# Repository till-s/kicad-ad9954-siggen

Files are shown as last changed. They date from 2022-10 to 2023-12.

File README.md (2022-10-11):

# Simple 1Hz-100MHz Signal Generator with AD9954

This project implements a simple sine-wave generator from a few Hz
to ~100MHz. The Reference/sampling frequency is 400MHz.
The output is buffered by a OP859 amplifier which does level-shifting,
and differential to single-ended conversion.

An analog LPF at the output supresses higher harmonics and provides
the DC-coupled signal into a 50 Ohm load (i.e., the filter was
designed for a 50Ohm termination). The ripple over the frequency range
is in the order of 1dB.

The output amplitude can be (digitally) scaled from ~1Vp (0.7V RMS) down
to 0Vp.

The AD9954 is programmed via USB (USB-SPI converter) by a simple python
software (in the sw/ subdirectory). Power is supplied by USB as well.

The assembled PCB fits into a Hammond 1455D601 extruded aluminum box
(60mm x 42.5mm x 23mm).

The PCB requires 4 layers.

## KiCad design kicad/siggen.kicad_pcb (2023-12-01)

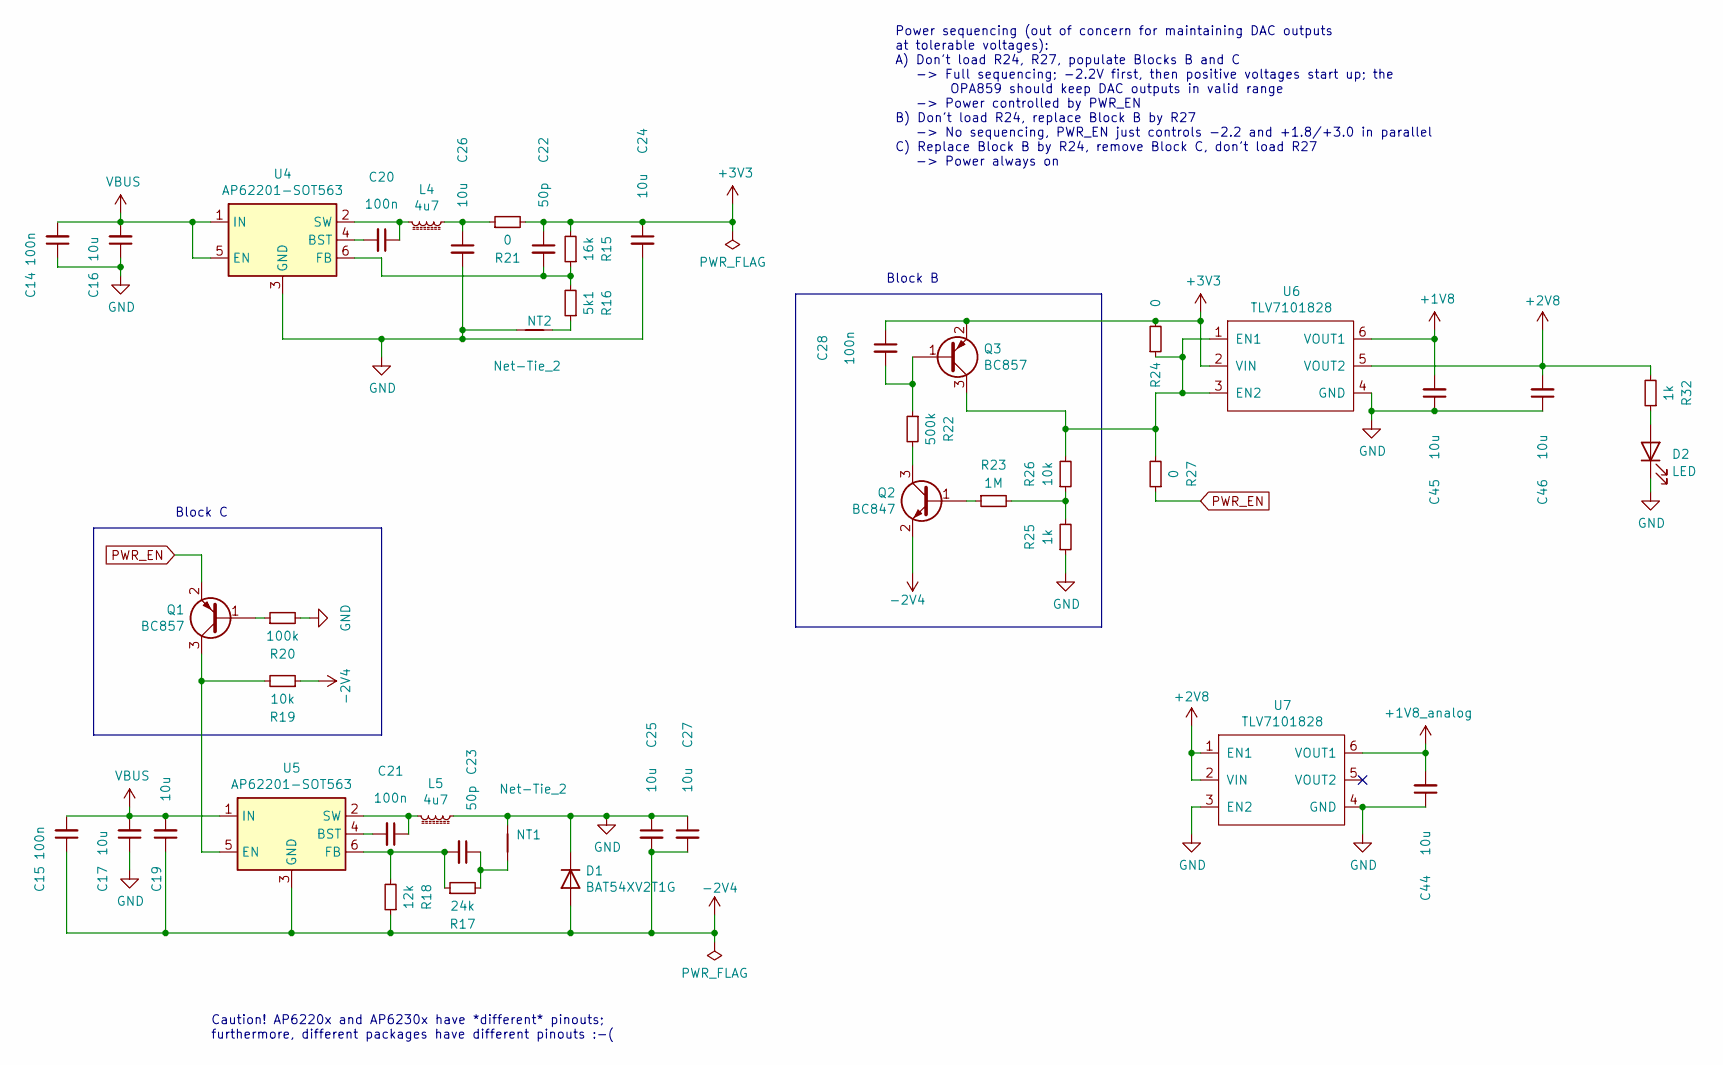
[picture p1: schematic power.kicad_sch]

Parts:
C14, C15, C20, C21, C28: 100n; C_0603_1608Metric
C16, C17, C19, C24, C25, C26, C27, C44, C45, C46: 10u; C_1206_3216Metric
C22, C23: 50p; C_0603_1608Metric
D1: BAT54XV2T1G; D_SOD-523
D2: LED; LED_0603_1608Metric
L4, L5: 4u7; L_Taiyo-Yuden_NR-50xx
NT1, NT2: Net-Tie_2; NetTie-2_SMD_Pad0.5mm
Q1, Q3: BC857; SOT-23
Q2: BC847; SOT-23
R15: 16k; R_0603_1608Metric
R16: 5k1; R_0603_1608Metric
R17: 24k; R_0603_1608Metric
R18: 12k; R_0603_1608Metric
R19, R26: 10k; R_0603_1608Metric
R20: 100k; R_0603_1608Metric
R21, R24, R27: 0; R_0603_1608Metric
R22: 500k; R_0603_1608Metric
R23: 1M; R_0603_1608Metric
R25, R32: 1k; R_0603_1608Metric
U4, U5: AP62201-SOT563; SOT-563-adjusted
U6, U7: TLV7101828; WSON-6_1.5x1.5mm_P0.5mm

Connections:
+1V8: C45.2, U6.6 (VOUT1); also elsewhere on the board
+1V8_analog: C44.2, U7.6 (VOUT1); also elsewhere on the board
+2V8: C46.2, R32.2, U6.5 (VOUT2), U7.1 (EN1), U7.2 (VIN); also elsewhere on the board
+3V3: C22.1, C24.1, C28.1, Q3.2 (E), R15.2, R21.2, R24.2, U6.2 (VIN); also elsewhere on the board
-2V4: C15.1, C19.1, C25.2, C27.2, D1.2 (A), Q2.2 (E), R18.1, R19.1, U5.3 (GND); also elsewhere on the board
GND: C14.1, C16.1, C17.1, C24.2, C25.1, C26.2, C27.1, C44.1, C45.1, C46.1, D1.1 (K), D2.1 (K), L5.1, NT1.1, NT2.2, R20.2, R25.1, U4.3 (GND), U6.4 (GND), U7.3 (EN2), U7.4 (GND); also elsewhere on the board
unnamed: C23.1, NT1.2, R17.2
unnamed: C26.1, L4.1, R21.1
unnamed: D2.2 (A), R32.1
unnamed: NT2.1, R16.1
unnamed: Q1.1 (B), R20.1
unnamed: Q1.3 (C), R19.2, U5.5 (EN)
unnamed: Q2.1 (B), R23.1
unnamed: Q2.3 (C), R22.2
unnamed: C28.2, Q3.1 (B), R22.1
unnamed: Q3.3 (C), R24.1, R26.2, R27.2, U6.1 (EN1), U6.3 (EN2)
unnamed: R23.2, R25.2, R26.1
unnamed: C20.2, U4.4 (BST)
unnamed: C22.2, R15.1, R16.2, U4.6 (FB)
unnamed: C20.1, L4.2, U4.2 (SW)
unnamed: C21.2, U5.4 (BST)
unnamed: C23.2, R17.1, R18.2, U5.6 (FB)
unnamed: C21.1, L5.2, U5.2 (SW)
PWR_EN: Q1.2 (E), R27.1; also elsewhere on the board
VBUS: C14.2, C15.2, C16.2, C17.2, C19.2, U4.1 (IN), U4.5 (EN), U5.1 (IN); also elsewhere on the board

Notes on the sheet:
Block B
Power sequencing (out of concern for maintaining DAC outputs at tolerable voltages): A) Don't load R24, R27, populate Blocks B and C -> Full sequencing; -2.2V first, then positive voltages start up; the OPA859 should keep DAC outputs in valid range -> Power controlled by PWR_EN B) Don't load R24, r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
Block C
Caution! AP6220x and AP6230x have *different* pinouts; furthermore, different packages have different pinouts :-(

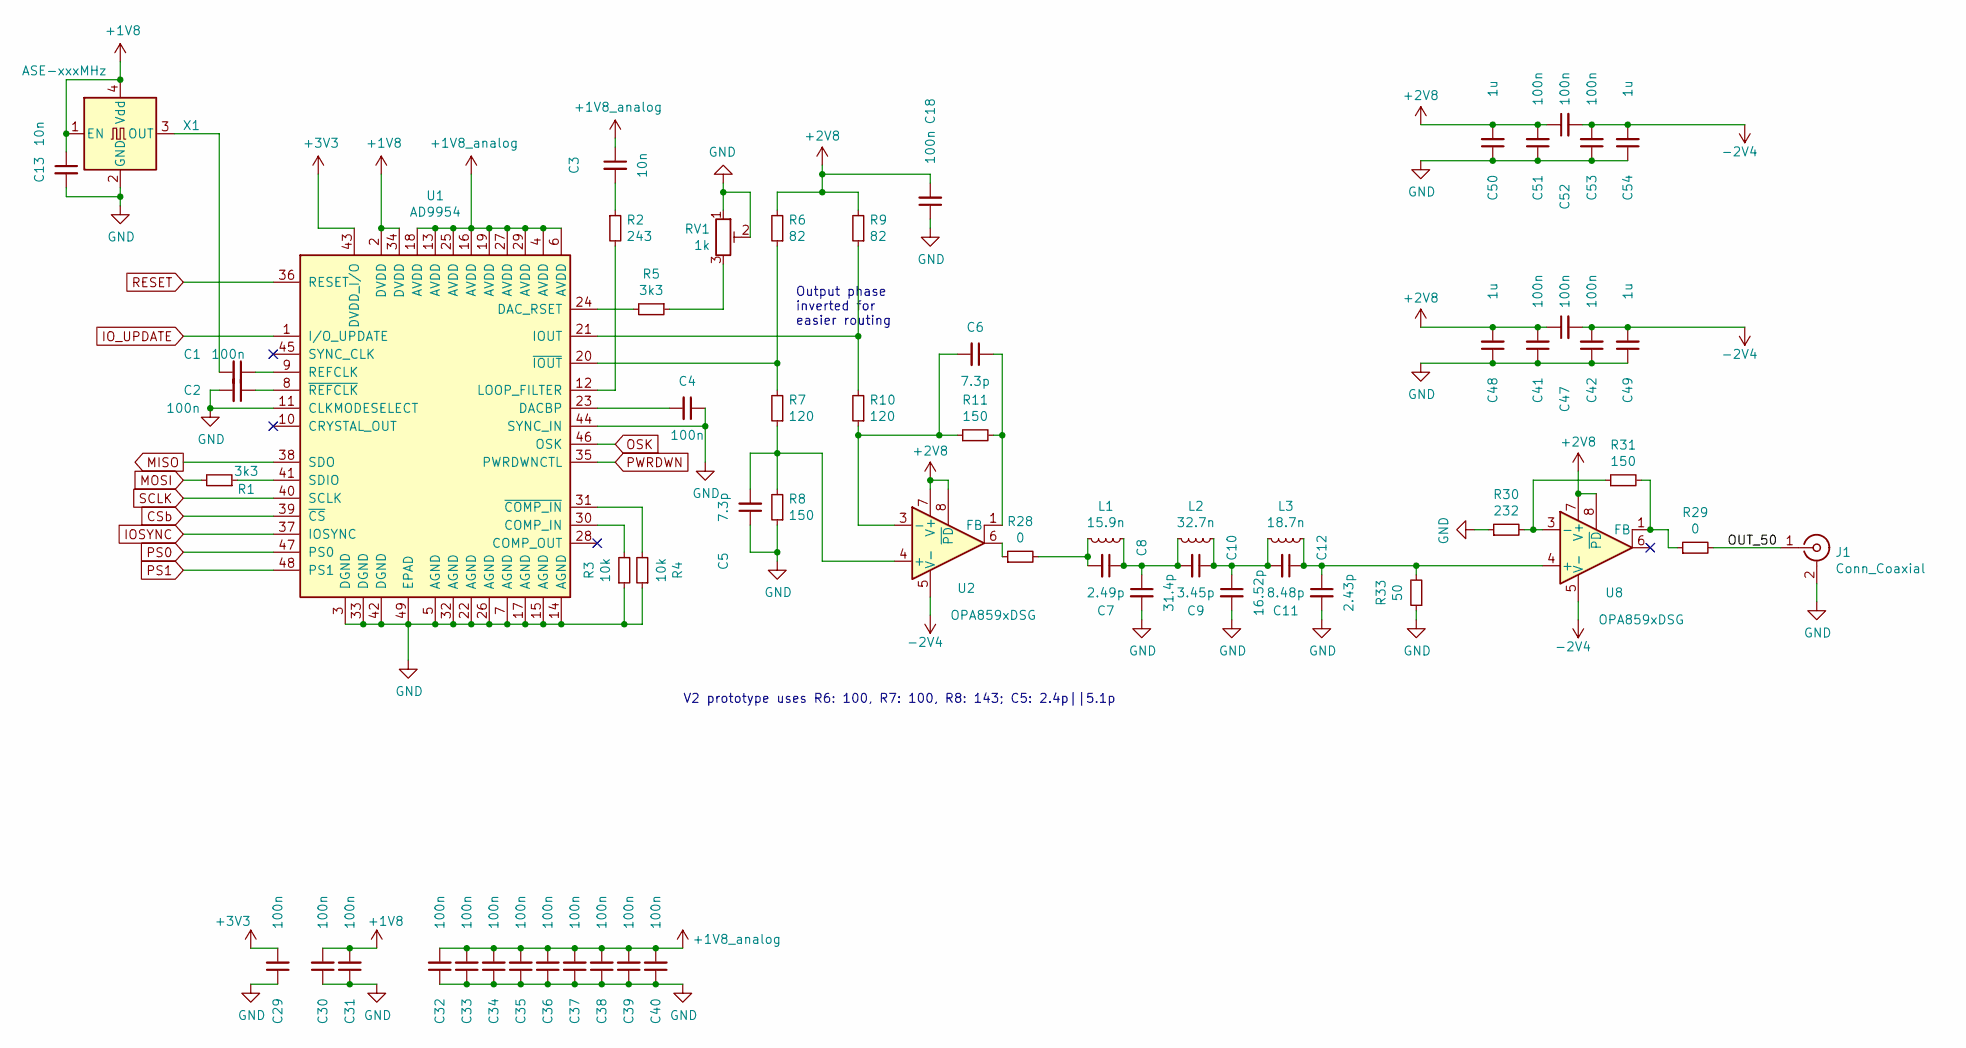
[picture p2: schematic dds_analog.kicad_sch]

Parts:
C1, C2: 100n; C_0603_1608Metric
C3, C13: 10n; C_0603_1608Metric
C4, C18, C29, C30, C31, C32, C33, C34, C35, C36, C37, C38, C39, C40, C41, C42, C47, C51, C52, C53: 100n; C_0402_1005Metric
C5, C6: 7.3p; C_0402_1005Metric
C7: 2.49p; C_0402_1005Metric
C8: 31.4p; C_0603_1608Metric
C9: 3.45p; C_0402_1005Metric
C10: 16.52p; C_0402_1005Metric
C11: 8.48p; C_0402_1005Metric
C12: 2.43p; C_0402_1005Metric
C48, C49, C50, C54: 1u; C_0805_2012Metric
J1: Conn_Coaxial; BNC_Molex_0731713150
L1: 15.9n; L_0603_1608Metric
L2: 32.7n; L_0603_1608Metric
L3: 18.7n; L_0603_1608Metric
R1, R5: 3k3; R_0603_1608Metric
R2: 243; R_0603_1608Metric
R3, R4: 10k; R_0603_1608Metric
R6, R9: 82; R_0402_1005Metric
R7, R10: 120; R_0402_1005Metric
R8, R11, R31: 150; R_0402_1005Metric
R28, R29: 0; R_0402_1005Metric
R30: 232; R_0402_1005Metric
R33: 50; R_0402_1005Metric
RV1: 1k; Bourns_PVG5A_Trimmer
U1: AD9954; TQFP-48-1EP_7x7mm_P0.5mm_EP3.5x3.5mm
U2, U8: OPA859xDSG; WSON-8-1EP_2x2mm_P0.5mm_EP0.9x1.6mm
X1: ASE-xxxMHz; Oscillator_SMD_Abracon_ASE-4Pin_3.2x2.5mm

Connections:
+1V8: C13.1, C30.2, C31.2, U1.2 (DVDD), U1.34 (DVDD), X1.1 (EN), X1.4 (Vdd); also elsewhere on the board
+1V8_analog: C3.1, C32.2, C33.2, C34.2, C35.2, C36.2, C37.2, C38.2, C39.2, C40.2, U1.4 (AVDD), U1.6 (AVDD), U1.13 (AVDD), U1.16 (AVDD), U1.18 (AVDD), U1.19 (AVDD), U1.25 (AVDD), U1.27 (AVDD), U1.29 (AVDD); also elsewhere on the board
+2V8: C18.2, C41.2, C47.1, C48.2, C50.2, C51.2, C52.1, R6.2, R9.2, U2.7 (V+), U2.8 (~PD), U8.7 (V+), U8.8 (~PD); also elsewhere on the board
+3V3: C29.2, U1.43 (DVDD_I/O); also elsewhere on the board
-2V4: C42.2, C47.2, C49.2, C52.2, C53.2, C54.2, U2.5 (V-), U2.9 (V-), U8.5 (V-), U8.9 (V-); also elsewhere on the board
/dds_analog/OUT_50: J1.1 (In), R29.2
CSb: U1.39 (~CS); also elsewhere on the board
GND: C2.2, C4.1, C5.1, C8.2, C10.2, C12.2, C13.2, C18.1, C29.1, C30.1, C31.1, C32.1, C33.1, C34.1, C35.1, C36.1, C37.1, C38.1, C39.1, C40.1, C41.1, C42.1, C48.1, C49.1, C50.1, C51.1, C53.1, C54.1, J1.2 (Ext), R3.1, R4.1, R8.1, R30.1, R33.1, RV1.1, RV1.2, U1.3 (DGND), U1.5 (AGND), U1.7 (AGND), U1.11 (CLKMODESELECT), U1.14 (AGND), U1.15 (AGND), U1.17 (AGND), U1.22 (AGND), U1.26 (AGND), U1.32 (AGND), U1.33 (DGND), U1.42 (DGND), U1.44 (SYNC_IN), U1.49 (EPAD), X1.2 (GND); also elsewhere on the board
IOSYNC: U1.37 (IOSYNC); also elsewhere on the board
IO_UPDATE: U1.1 (I/O_UPDATE); also elsewhere on the board
MISO: U1.38 (SDO); also elsewhere on the board
MOSI: R1.2; also elsewhere on the board
unnamed: C3.2, R2.1
unnamed: C7.1, C8.1, C9.2, L1.1, L2.2
unnamed: C7.2, L1.2, R28.2
unnamed: C9.1, C10.1, C11.2, L2.1, L3.2
unnamed: R5.1, RV1.3
unnamed: R28.1, U2.6
unnamed: R3.2, U1.30 (COMP_IN)
unnamed: C4.2, U1.23 (DACBP)
unnamed: R5.2, U1.24 (DAC_RSET)
unnamed: R9.1, R10.2, U1.21 (IOUT)
unnamed: R2.2, U1.12 (LOOP_FILTER)
unnamed: C1.1, U1.9 (REFCLK)
unnamed: R1.1, U1.41 (SDIO)
unnamed: R4.2, U1.31 (~COMP_IN)
unnamed: R6.1, R7.2, U1.20 (~IOUT)
unnamed: C2.1, U1.8 (~REFCLK)
unnamed: C5.2, R7.1, R8.2, U2.4 (+)
unnamed: C6.2, R10.1, R11.1, U2.3 (-)
unnamed: C6.1, R11.2, U2.1 (FB)
unnamed: C11.1, C12.1, L3.1, R33.2, U8.4 (+)
unnamed: R30.2, R31.1, U8.3 (-)
unnamed: R29.1, R31.2, U8.1 (FB)
unnamed: C1.2, X1.3 (OUT)
OSK: U1.46 (OSK); also elsewhere on the board
PS0: U1.47 (PS0); also elsewhere on the board
PS1: U1.48 (PS1); also elsewhere on the board
PWRDWN: U1.35 (PWRDWNCTL); also elsewhere on the board
RESET: U1.36 (RESET); also elsewhere on the board
SCLK: U1.40 (SCLK); also elsewhere on the board

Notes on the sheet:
V2 prototype uses R6: 100, R7: 100, R8: 143; C5: 2.4p||5.1p
Output phase inverted for easier routing

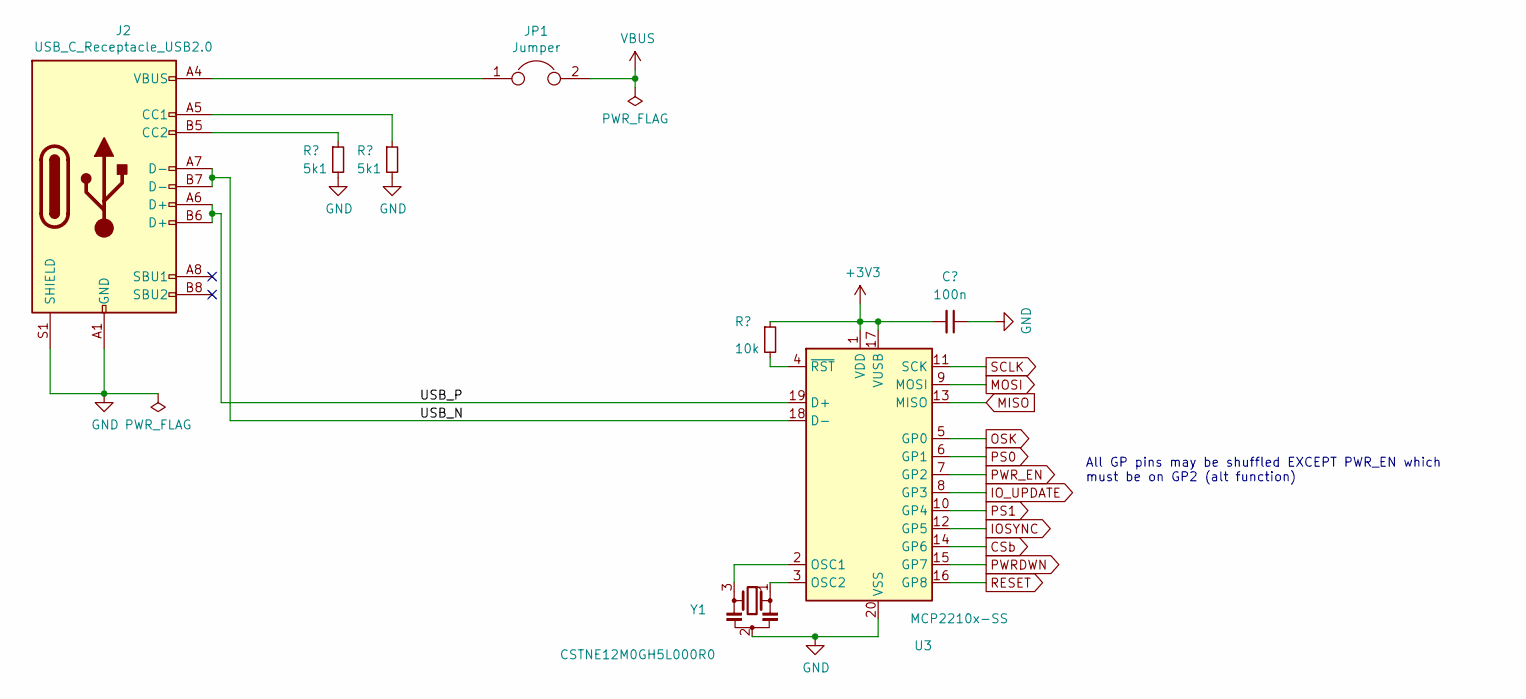
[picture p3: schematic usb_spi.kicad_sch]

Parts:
C43: 100n; C_0603_1608Metric
J2: USB_C_Receptacle_USB2.0; USB_C_Receptacle_Molex_2171790001_16P_TopMnt_Horizontal
JP1: Jumper; PinHeader_1x02_P1.27mm_Vertical_reduced_crtyd
R12, R13: 5k1; R_0603_1608Metric
R14: 10k; R_0603_1608Metric
U3: MCP2210x-SS; SSOP-20_5.3x7.2mm_P0.65mm
Y1: CSTNE12M0GH5L000R0; Resonator_SMD_muRata_CSTxExxV-3Pin_3.0x1.1mm

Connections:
+3V3: C43.2, R14.1, U3.1 (VDD), U3.17 (VUSB); also elsewhere on the board
/usb_spi/USB_N: J2.A7 (D-), J2.B7 (D-), U3.18 (D-)
/usb_spi/USB_P: J2.A6 (D+), J2.B6 (D+), U3.19 (D+)
CSb: U3.14 (GP6); also elsewhere on the board
GND: C43.1, J2.A1 (GND), J2.A12 (GND), J2.B1 (GND), J2.B12 (GND), J2.S1 (SHIELD), R12.2, R13.2, U3.20 (VSS), Y1.2; also elsewhere on the board
IOSYNC: U3.12 (GP5); also elsewhere on the board
IO_UPDATE: U3.8 (GP3); also elsewhere on the board
MISO: U3.13 (MISO); also elsewhere on the board
MOSI: U3.9 (MOSI); also elsewhere on the board
unnamed: J2.A5 (CC1), R13.1
unnamed: J2.B5 (CC2), R12.1
unnamed: J2.A4 (VBUS), J2.A9 (VBUS), J2.B4 (VBUS), J2.B9 (VBUS), JP1.1
unnamed: U3.2 (OSC1), Y1.3
unnamed: U3.3 (OSC2), Y1.1
unnamed: R14.2, U3.4 (~RST)
OSK: U3.5 (GP0); also elsewhere on the board
PS0: U3.6 (GP1); also elsewhere on the board
PS1: U3.10 (GP4); also elsewhere on the board
PWRDWN: U3.15 (GP7); also elsewhere on the board
PWR_EN: U3.7 (GP2); also elsewhere on the board
RESET: U3.16 (GP8); also elsewhere on the board
SCLK: U3.11 (SCK); also elsewhere on the board
VBUS: JP1.2; also elsewhere on the board

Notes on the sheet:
All GP pins may be shuffled EXCEPT PWR_EN which must be on GP2 (alt function)

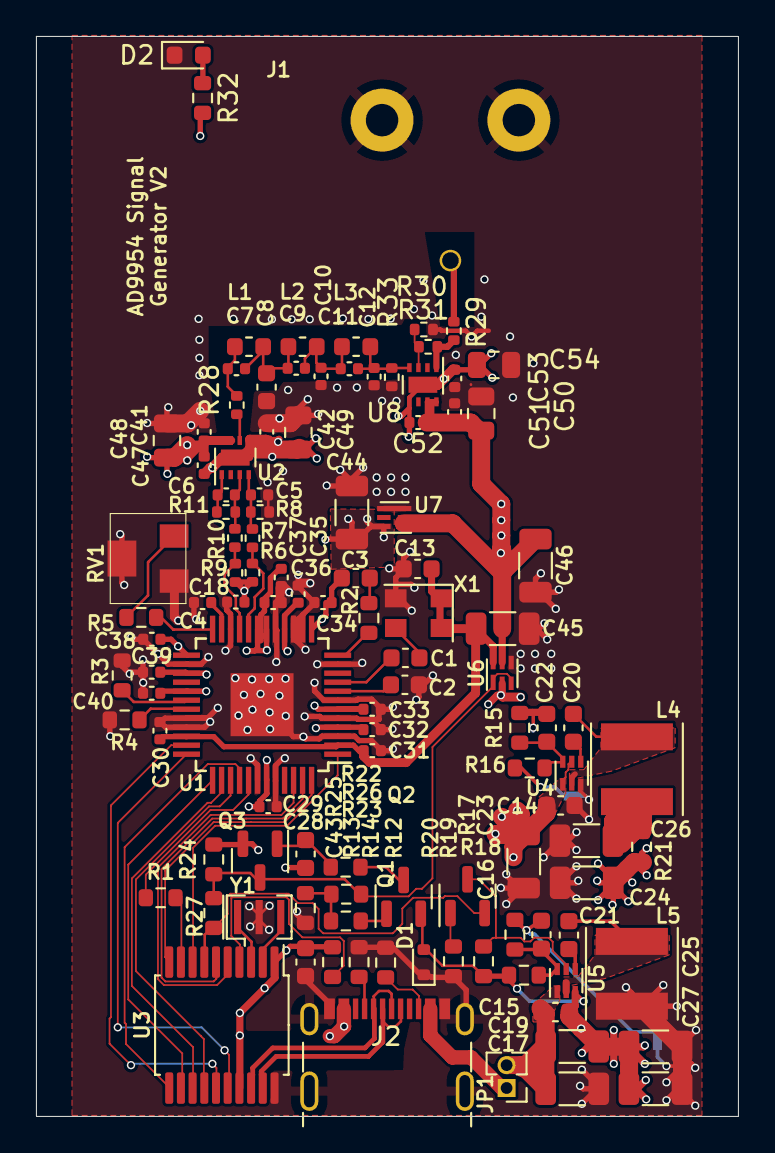
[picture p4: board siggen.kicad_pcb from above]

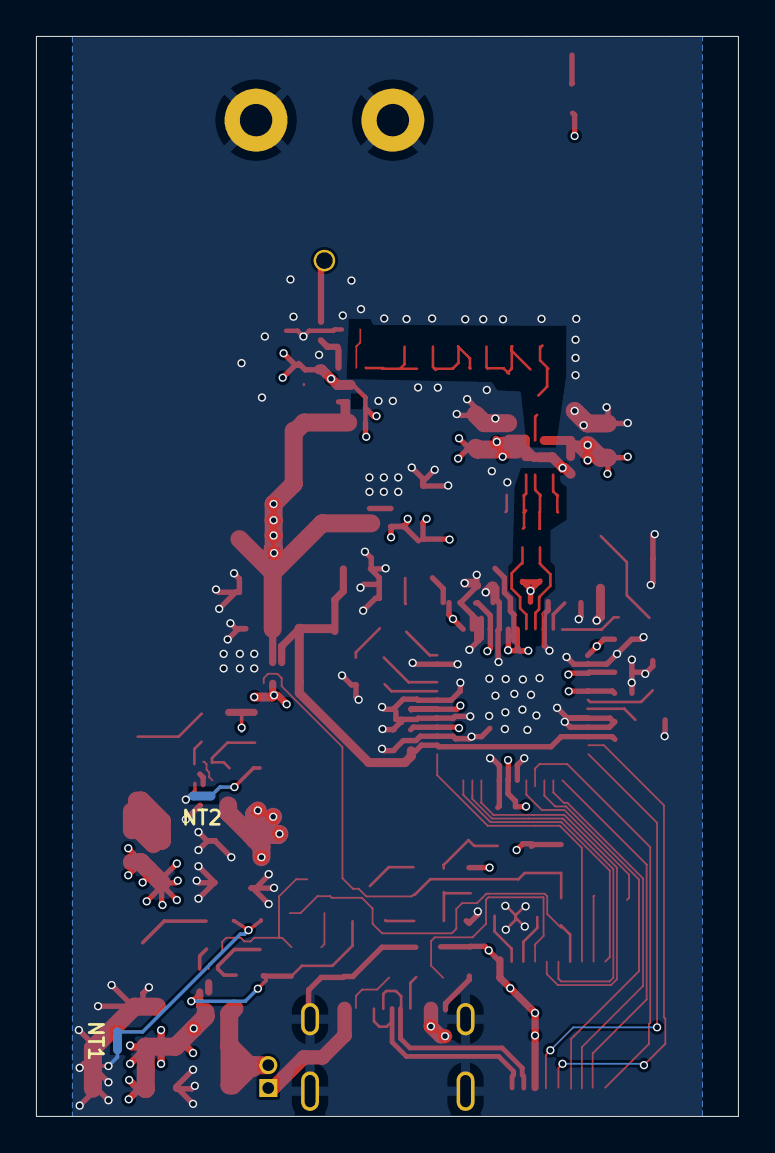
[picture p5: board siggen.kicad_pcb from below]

Board: 4 copper layers, 39.0 x 60.0 mm, 113 parts (2 on the bottom side), 68 nets.

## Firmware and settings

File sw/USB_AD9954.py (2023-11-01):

#!/usr/bin/env python3
import hidapi

class SigGen(object):
  PIN_OSK       = 0
  PIN_PS0       = 1
  PIN_PWR_EN    = 2
  PIN_IO_UPDATE = 3

  PIN_PS1       = 4
  PIN_IOSYNC    = 5
  PIN_CSb       = 6
  PIN_PWRDWN    = 7
  # Reset / PIN8 is input only -> shorted to PIN_PWRDWN on V1 board
  # via solder bridge

  SPI_MODE = 0

  SPI_DIR_READ       = 0x80

  CMD_RD_GPIO_SETUP  = 0x20
  CMD_WR_GPIO_SETUP  = 0x21
  CMD_RD_GPIO_DIR    = 0x33
  CMD_WR_GPIO_DIR    = 0x32
  CMD_RD_GPIO_VALUE  = 0x31
  CMD_WR_GPIO_VALUE  = 0x30
  CMD_RD_SPI_SETUP   = 0x41
  CMD_WR_SPI_SETUP   = 0x40
  CMD_SPI_XFER       = 0x42
  CMD_SPI_CANCEL     = 0x11

  REG_CFR1           = 0x00
  CFR1_SDIO_IN       = (1<< 9)
  CFR1_OSK_EN        = (1<<25)
  CFR1_OSK_AUTO      = (1<<24)
  CFR1_CMP_PWRDWN    = (1<< 6)
  CFR1_SYNC_CLK_DIS  = (1<< 1)

  REG_CFR2           = 0x01
  CFR2_VCO_RNG_HI    = (1<< 2)
  CFR2_SHF_REF_MUL   = 3

  REG_ASF            = 0x02

  REG_FTW0           = 0x04

  REF_CLK_HZ         = 25.0e6

  def __init__(self, serial=None, dbg=False):
    self.dbg_       = dbg
    self.dev_       = hidapi.Device(vendor_id=0x4d8, product_id=0xde, serial_number=serial)
    self.rdGpio_    = bytearray(64)
    self.rdGpio_[0] = self.CMD_RD_GPIO_SETUP
    self.wrGpio_    = bytearray(64)
    self.wrGpio_[0] = self.CMD_WR_GPIO_VALUE
    rsp = self._io_(self.rdGpio_)
    if ( rsp[1] != 0 ):
      raise RuntimeError("Reading GPIO Status - error response")
    setGpio = bytearray(64)
    for i in range(64):
      setGpio[i] = rsp[i]
    setGpio[0] = self.CMD_WR_GPIO_SETUP
    setGpio[1] = 0
    setGpio[2] = 0
    setGpio[3] = 0
    for i in range(4, 4+9):
      setGpio[i] = 0   # GPIO
    setGpio[13] = 0x00 | (1<<self.PIN_PWR_EN) # all outputs zero, except PWR_EN
    setGpio[14] &= 0xfe
    setGpio[15] = 0x00 # all GPIO outputs
    setGpio[16] &= 0xfe
    self.wrGpio_[4] = setGpio[13]
    self._io_(setGpio, True)
    cmd = bytearray(64)
    cmd[0] = self.CMD_RD_SPI_SETUP
    rsp = self._io_(cmd)
    self.spiParms_ = bytearray(64)
    self.spiParms_[0] = self.CMD_WR_SPI_SETUP
    self.spiParms_[4:]= rsp[4:]
    self.spiParms_[20]= self.SPI_MODE
    self.sendSpiParms()
    cfr1  = self.CFR1_SDIO_IN
    cfr1 |= self.CFR1_OSK_EN 
    cfr1 |= self.CFR1_CMP_PWRDWN 
    cfr1 |= self.CFR1_SYNC_CLK_DIS
    self.regWrite(self.REG_CFR1, cfr1)
    self.setRefClk(400.0E6)

  def setRefClk(self, rate):
    m = int( round( rate/self.REF_CLK_HZ ) )
    if ( m > 20 ):
      raise RuntimeError("setRefClk() -- requested rate too high")
    if ( m < 4 ):
      m = 1
    self.sysClkHz_ = m * self.REF_CLK_HZ
    print("System Clock: {:g}".format(self.sysClkHz_))
    cfr2 = self.regRead( self.REG_CFR2 )
    cfr2 &= ~ 0xfc
    cfr2 |= (m << self.CFR2_SHF_REF_MUL)
    if ( self.sysClkHz_ > 250.0E6 ):
      cfr2 |= self.CFR2_VCO_RNG_HI
    self.regWrite( self.REG_CFR2, cfr2 )

  def setAmplitudeScale(self, scl):
    if ( scl < 0 or scl > 1.0 ):
      raise ValueError("SigGen.setAmplitudeScale() -- scale factor not in 0..1")
    v = self.regRead( self.REG_ASF )
    v &= ~0x3fff
    v |= int(0x3fff*scl)
    self.regWrite( self.REG_ASF, v)

  def getAmplitudeScale(self):
    v = self.regRead( self.REG_ASF )
    return float(v & 0x3fff)/0x3fff

  def setFrequencyHz(self, f, ftw1 = False):
    ftw = int(round(f/self.sysClkHz_ * 2.0**32))
    if ( ftw < 0 or ftw > 2**31 ):
      raise ValueError("SigGen.setFrequency() -- value out of range")
    if ftw1:
      reg = self.REG_FTW1
    else:
      reg = self.REG_FTW0
    self.regWrite(reg, ftw)

  def getFrequencyHz(self, ftw1 = False):
    if ftw1:
      reg = self.REG_FTW1
    else:
      reg = self.REG_FTW0
    v = self.regRead( reg )
    return v/2.0**32 * self.sysClkHz_

  def _io_(self, buf, check1 = False):
    self.dev_.write(buf)
    rsp = self.dev_.read(64)
    if ( check1 and ( rsp[1] != 0 ) ):
      raise RuntimeError("IO Error response {:d}".format(rsp[1]))
    return rsp

  def sendSpiParms(self):
    rsp = self._io_(self.spiParms_)
    if ( rsp[1] != 0 ):
      raise RuntimeError("Setting SPI parameters failed")

  def flashGpio(self, n):
    self.setGpio( n, 1 )
    self.setGpio( n, 0 )

  def ioSync(self):
    self.flashGpio( self.PIN_IOSYNC )

  def ioUpdate(self):
    self.flashGpio( self.PIN_IO_UPDATE )

  def setGpio(self, n, val):
    if ( n < 0 or n > 8 ):
      raise RuntimeError("Invalid GPIO pin")
    i   = 4 + int(n / 8)
    n   = n % 8
    if ( val != 0 ):
      self.wrGpio_[i] |=  (1<<n)
    else:
      self.wrGpio_[i] &= ~(1<<n)
    self._io_(self.wrGpio_, True)

  def getGpios(self):
    d = bytearray(64)
    d[0] = self.CMD_RD_GPIO_VALUE
    rsp = self._io_(d, True)
    return rsp[4] | ((rsp[5] & 1) << 8)

  def powerOn(self):
    self.setGpio(2, 1)

  def powerOff(self):
    self.setGpio(2, 0)

  def spi(self, buf = bytearray(0)):
    if (type(buf) != bytearray) or (len(buf) > 60):
      raise RuntimeError("SigGen.spi: invalid data")
    snd = bytearray(64)
    snd[0] = self.CMD_SPI_XFER
    snd[1] = len(buf)
    snd[4:4+len(buf)] = buf
    if ( len(buf) > 0 ):
      if ( ((self.spiParms_[19] << 8) | self.spiParms_[18]) != len(buf) ):
        self.spiParms_[19] = 0
        self.spiParms_[18] = len(buf)
        self.sendSpiParms()
    rsp = self._io_(snd)
    if   ( rsp[1] == 0xf7 ):
      raise RuntimeError("SPI: bus not available")
    elif ( rsp[1] == 0x00 ):
      got = rsp[2]
      if (self.dbg_):
        print("SPI status 0x{:x}, got {:d}".format(rsp[3], got))
      return rsp[4:4+got]
    elif ( rsp[1] == 0xf8 ):
      raise RuntimeError("SPI: xfer in progress")
    else:
      raise RuntimeError("SPI: Unexpected response")

  def spiCancel(self):
    snd = bytearray(64)
    snd[0] = self.CMD_SPI_CANCEL
    rsp = self._io_(snd)
    print("SPI cancel: no ext req: {:d}, owner {:d}".format( rsp[2], rsp[3]))

  def regLen(self, ri):
    ll = [4, 3, 2, 1, 4, 2, 5, 5, 5, 5]
    if ( ri < 0 or ri >= len(ll) ):
      raise RuntimeError("SigGen.regLen() - invalid register index")
    return ll[ri]

  def regWrite(self, ri, val):
    d = bytearray(self.regLen(ri) + 1)
    for i in range(-1, -len(d), -1):
      d[i]  = val % 256
      val >>= 8
    d[0] = ri
    self.spi( d )
    self.spi()
    self.ioUpdate()
    
  def regRead(self, ri):
    d = bytearray(self.regLen(ri) + 1)
    d[0] = ri | self.SPI_DIR_READ
    self.spi( d )
    v = 0
    for x in self.spi()[1:]:
      v = (v<<8) | x
    return v
 
#sg=SigGen()
# usage example:
# sg.setFrequencyHz(1.3E6)
# scale between 0..1
# sg.setAmplitudeScale(0.2)

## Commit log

2022-10-11 initial import
    [dds_analog.sch, fe_test_v2.sch, power.sch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]
2022-10-11 added pcb file
    [siggen-v1.kicad_pcb]
2022-10-11 removed frontent/amp test circuit
    This circuit had shared the PCB for cost reasons.
    [dds_analog.sch, fe_test_v2.sch, power.sch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]
2022-10-11 moved RV1 (pot) away from board edge (README.errata)
    [siggen-v1.kicad_pcb]
2022-10-11 renamed (removed 'v1' in filenames)
    [siggen.kicad_pcb, siggen.sch]
2022-10-11 renamed objects that had '-v1' in their names
    [dds_analog.sch]
2022-10-17 updated README.errata (recommend adding output stage)
2023-11-01 Added output buffer; power LED
    [dds_analog.kicad_sch, power.kicad_sch, siggen.kicad_pcb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]
2023-11-01 prepare for jlcpcb order (v2)
    [dds_analog.kicad_sch, siggen.kicad_pcb, usb_spi.kicad_sch]
2023-12-01 modified a few values (as loaded on v2 prototype board)
    [dds_analog.kicad_sch, power.kicad_sch, siggen.kicad_pcb]
2023-12-01 emphasize that the values are for the V2 *prototype*
    The final version uses different voltages: 2.8/-2.4 (vs 3.0/-2.2).
    [dds_analog.kicad_sch]
2023-12-01 changed values in schematic for v2 board
    Most notably: moved from +3.0/-2.2V to +2.8/-2.4V analog supply.
    This required changing the diff-amp resistors to stay within
    the common-mode range of the AD9954 and the OPA859.
    [dds_analog.kicad_sch, power.kicad_sch, siggen.kicad_pcb]
